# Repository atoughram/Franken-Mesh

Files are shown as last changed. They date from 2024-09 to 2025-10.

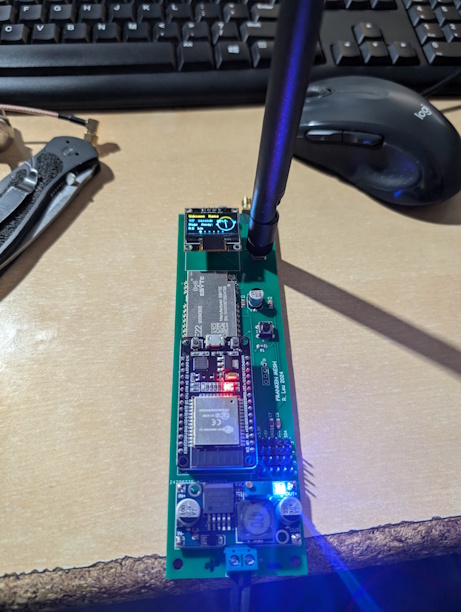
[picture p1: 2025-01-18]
images/PXL_20240928_021302629.jpg

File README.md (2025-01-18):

# Franken-Mesh
## DIY 1W LORA Node for Meshtastic

A Meshtastic project using a 30dbm (1W) LORA Radio (E22-900M30S) and an EPS32-DEVKIT-V1.  The circuit also adds four I2C ports for other sensors like a BME280 enviromental sensor, or any other sensor suported by Meshtastic.  There is also a TTL serial port for use with a GPS module and a ssd1306 connector if a Oled screen is wanted.

I've used this for both mobile and fixed operations with good luck.  There are STL files for a 3d printing a simple enclosure for the PCB.

![Franken-Mesh] (images/PXL_20240928_021302629.jpg) 

MIT License

Copyright (c) 2025 atoughram

Permission is hereby granted, free of charge, to any person obtaining a copy
of this software and associated documentation files (the "Software"), to deal
in the Software without restriction, including without limitation the rights
to use, copy, modify, merge, publish, distribute, sublicense, and/or sell
copies of the Software, and to permit persons to whom the Software is
furnished to do so, subject to the following conditions:

The above copyright notice and this permission notice shall be included in all
copies or substantial portions of the Software.

THE SOFTWARE IS PROVIDED "AS IS", WITHOUT WARRANTY OF ANY KIND, EXPRESS OR
IMPLIED, INCLUDING BUT NOT LIMITED TO THE WARRANTIES OF MERCHANTABILITY,
FITNESS FOR A PARTICULAR PURPOSE AND NONINFRINGEMENT. IN NO EVENT SHALL THE
AUTHORS OR COPYRIGHT HOLDERS BE LIABLE FOR ANY CLAIM, DAMAGES OR OTHER
LIABILITY, WHETHER IN AN ACTION OF CONTRACT, TORT OR OTHERWISE, ARISING FROM,
OUT OF OR IN CONNECTION WITH THE SOFTWARE OR THE USE OR OTHER DEALINGS IN THE
SOFTWARE.

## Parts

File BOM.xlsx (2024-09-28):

Description | Value | Reference | Qty | Footprint | Price | URL
Capacitor | 100nf | C2, C3, C4, C5, C7, C8, C9, C10 | 8 | Resistor_SMD:R_1206_3216Metric_Pad1.30x1.75mm_HandSolder | $1.26 | https://www.aliexpress.us/item/3256805505305288.html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
Capacitor | 100uf | C1, C6 | 2 | Capacitor_SMD:CP_Elec_6.3x7.7 | $1.62 | https://www.aliexpress.us/item/3256804775943180.html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
Resistor | 10K | R1 | 1 | Resistor_SMD:R_1206_3216Metric_Pad1.30x1.75mm_HandSolder | $1.07 | https://www.aliexpress.us/item/3256805494865143.html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
Microcontroller | ESP32-DEVKIT-V1 | U1 | 1 |  | $3.79 | https://www.aliexpress.us/item/3256802944254383.html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
30dbm LORA Radio | E22-900M30S | U2 | 1 |  | $7.39 | https://www.aliexpress.us/item/2255800357606493.html
SMA Connector |  | J7, J8 | 1 | Connector_Coaxial:SMA_Amphenol_901-144_Vertical | $2.31 | https://www.aliexpress.us/item/3256802990049867.html
Switch |  | SW1 | 1 | Button_Switch_THT:SW_PUSH_6mm | $0.25 | https://www.aliexpress.us/item/3256802876527512.html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
Display | SSD1306 |  | 1 |  | $1.65 | https://www.aliexpress.us/item/3256807290188213.html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
Buck Converter | LM2596 | U3 | 1 |  | $1.23 | https://www.aliexpress.us/item/3256806546818317.html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
Screw Terminal |  | J9 | 1 | TerminalBlock:TerminalBlock_bornier-2_P5.08mm | $1.32 | https://www.aliexpress.us/item/3256806456550715.html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
Male 5 pin Header |  | J3 - J6 | 4 | Connector_PinHeader_2.54mm:PinHeader_1x05_P2.54mm_Vertical | $1.91 | https://www.aliexpress.us/item/2255800687544049.html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
Female 15 pin Header |  |  | 2 |  | $1.91 | https://www.aliexpress.us/item/2255800687544049.html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

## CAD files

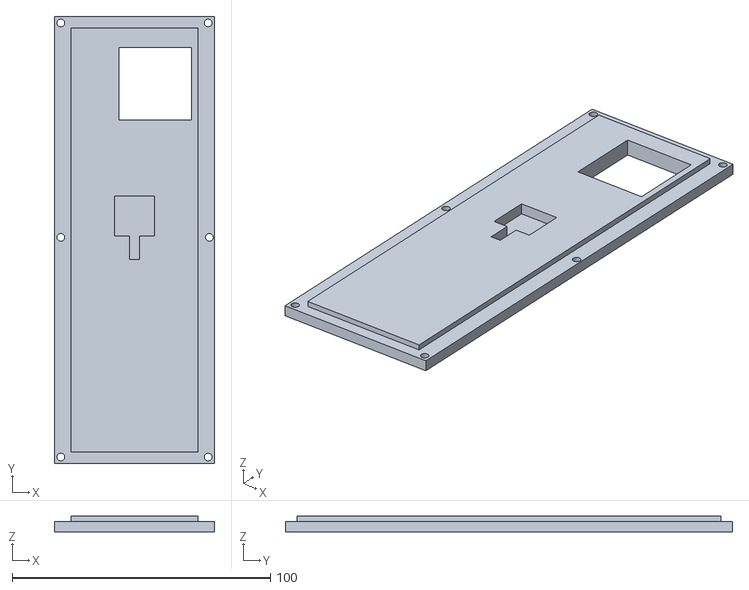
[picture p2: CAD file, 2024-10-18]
STL/Frankenmesh Top w GPS.stl
62.0 x 173.0 x 6.00

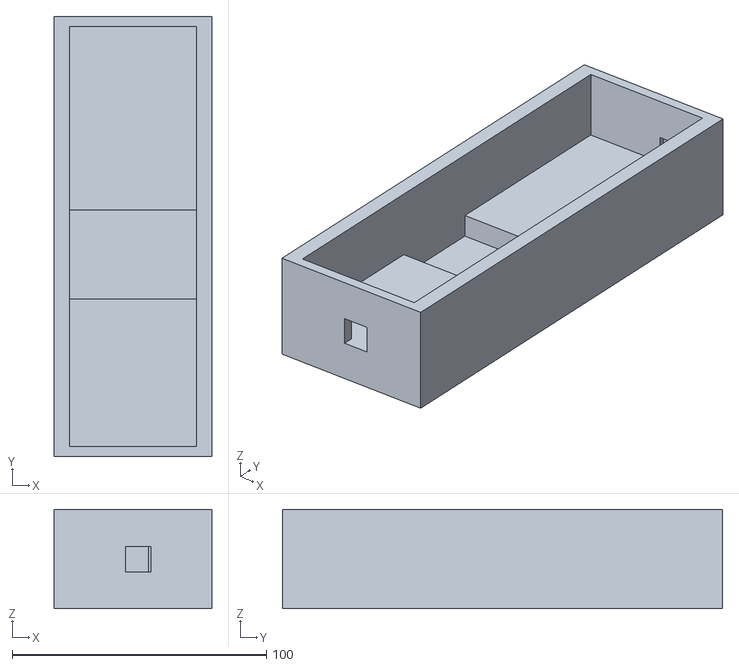
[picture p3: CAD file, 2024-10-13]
STL/Frankmesh Mobile Box Bottom with GPS.stl
62.0 x 173.0 x 39.0

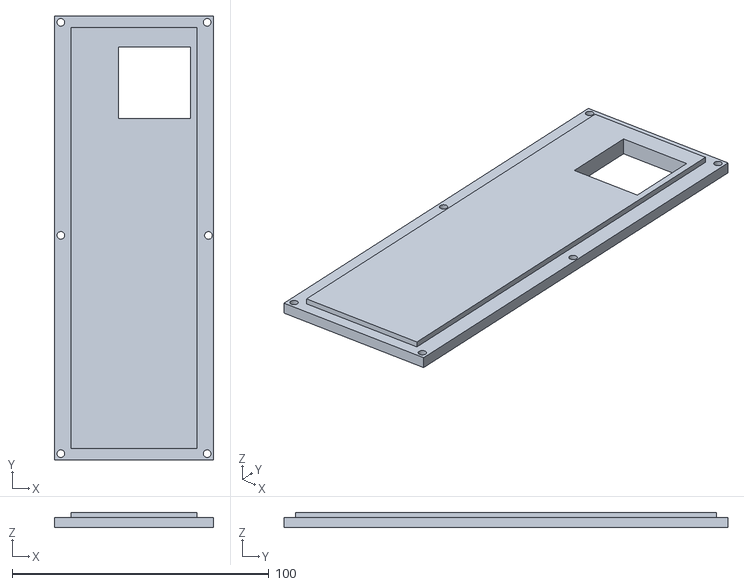
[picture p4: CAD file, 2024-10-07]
STL/Frankmesh Mobile Box Top (3).stl
62.0 x 173.0 x 6.00

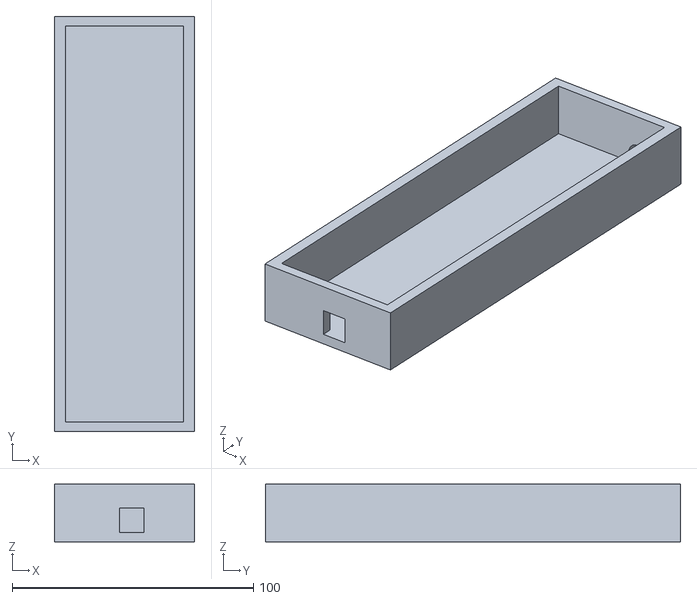
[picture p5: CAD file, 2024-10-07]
STL/Frankmesh Mobile Box Bottom (1).stl
58.0 x 172.0 x 24.0

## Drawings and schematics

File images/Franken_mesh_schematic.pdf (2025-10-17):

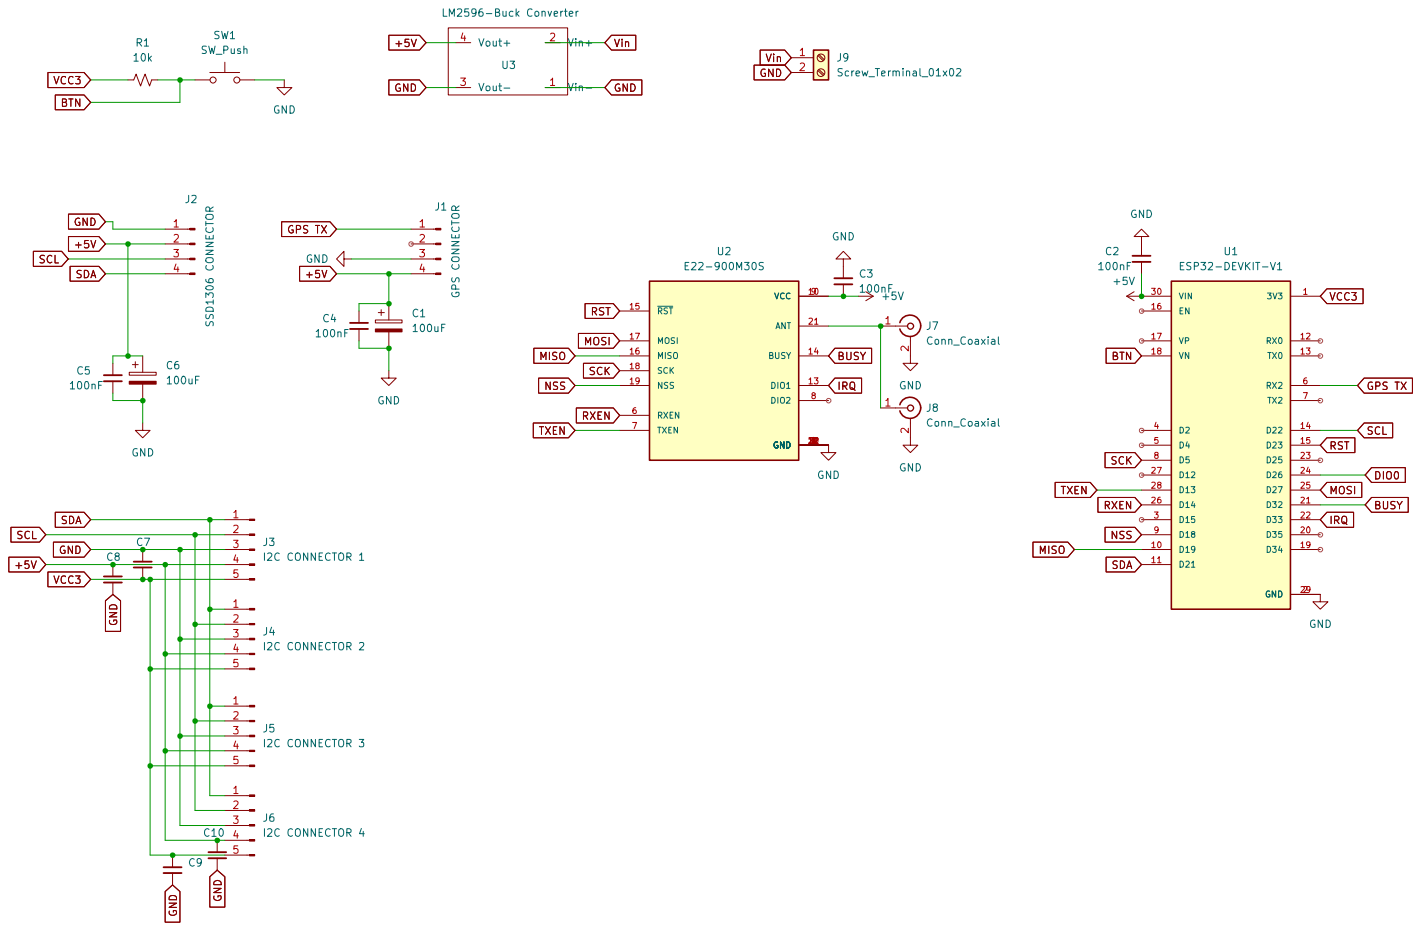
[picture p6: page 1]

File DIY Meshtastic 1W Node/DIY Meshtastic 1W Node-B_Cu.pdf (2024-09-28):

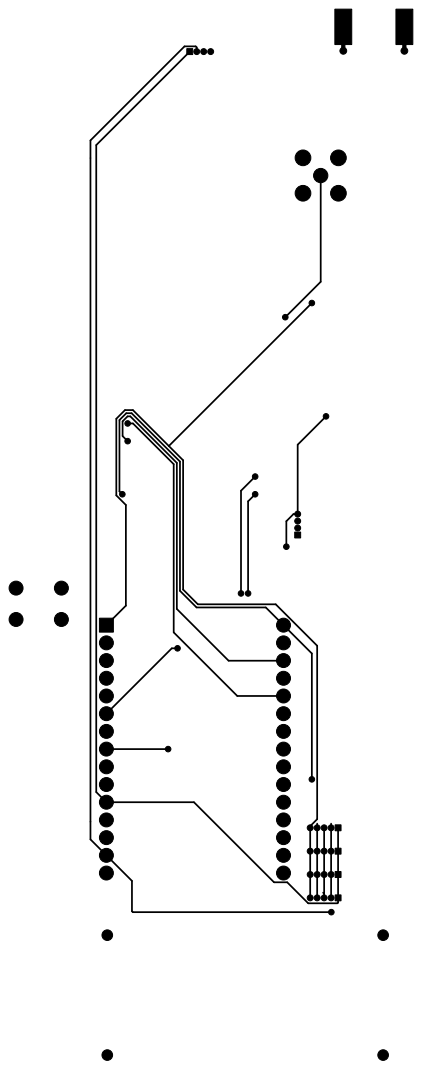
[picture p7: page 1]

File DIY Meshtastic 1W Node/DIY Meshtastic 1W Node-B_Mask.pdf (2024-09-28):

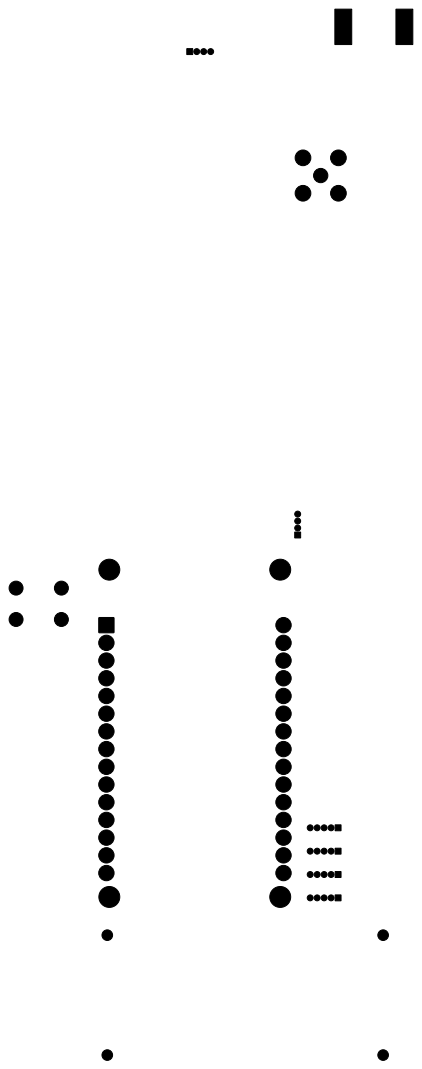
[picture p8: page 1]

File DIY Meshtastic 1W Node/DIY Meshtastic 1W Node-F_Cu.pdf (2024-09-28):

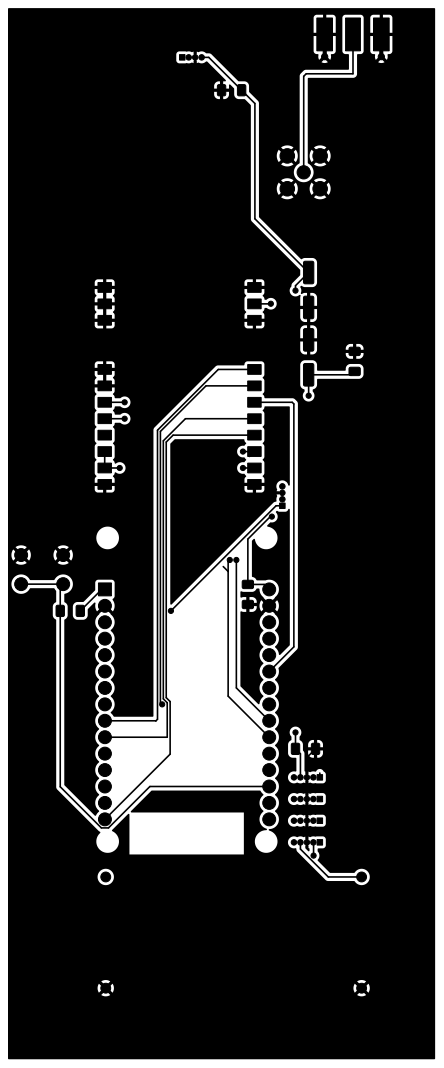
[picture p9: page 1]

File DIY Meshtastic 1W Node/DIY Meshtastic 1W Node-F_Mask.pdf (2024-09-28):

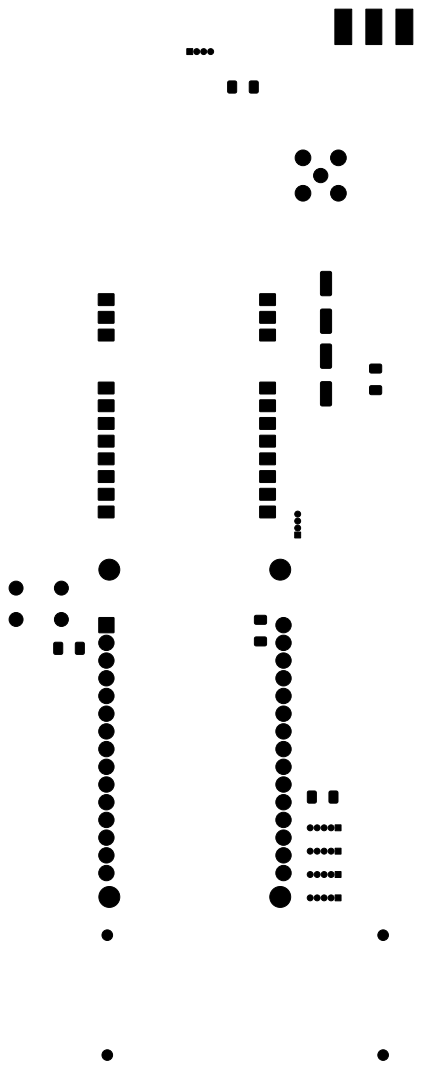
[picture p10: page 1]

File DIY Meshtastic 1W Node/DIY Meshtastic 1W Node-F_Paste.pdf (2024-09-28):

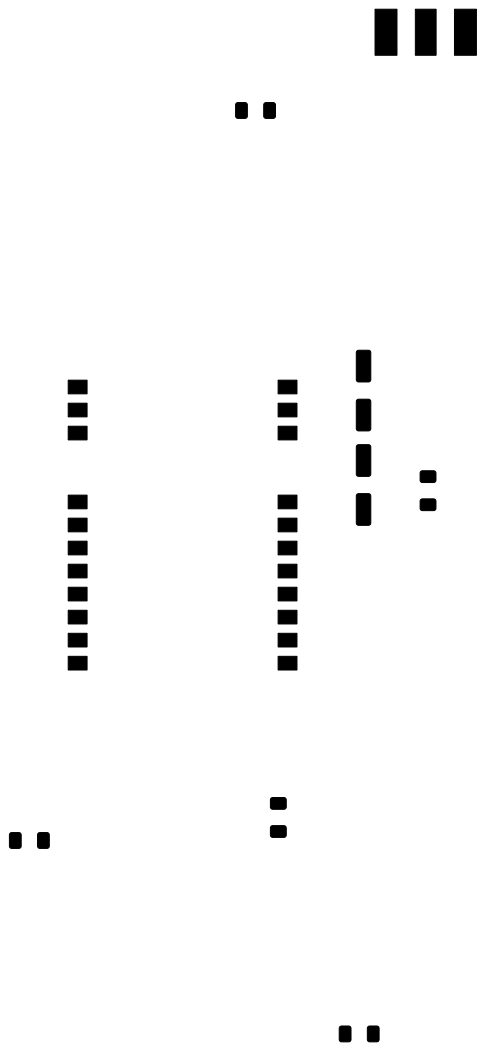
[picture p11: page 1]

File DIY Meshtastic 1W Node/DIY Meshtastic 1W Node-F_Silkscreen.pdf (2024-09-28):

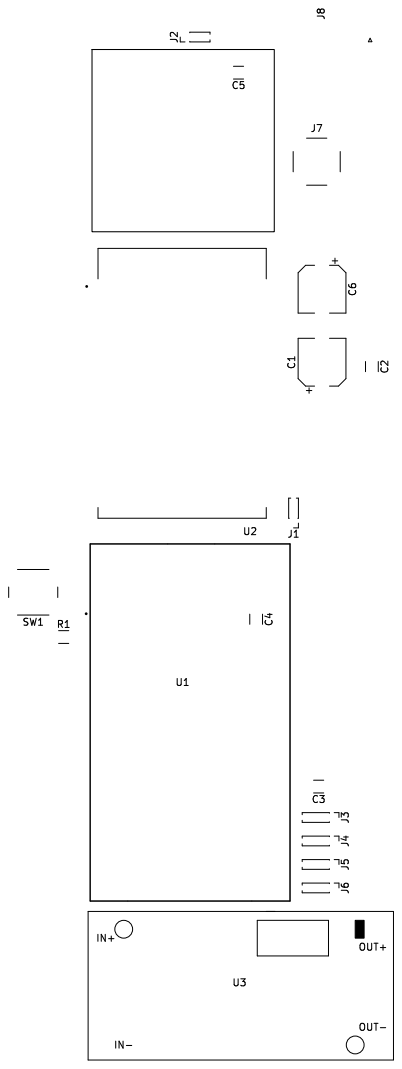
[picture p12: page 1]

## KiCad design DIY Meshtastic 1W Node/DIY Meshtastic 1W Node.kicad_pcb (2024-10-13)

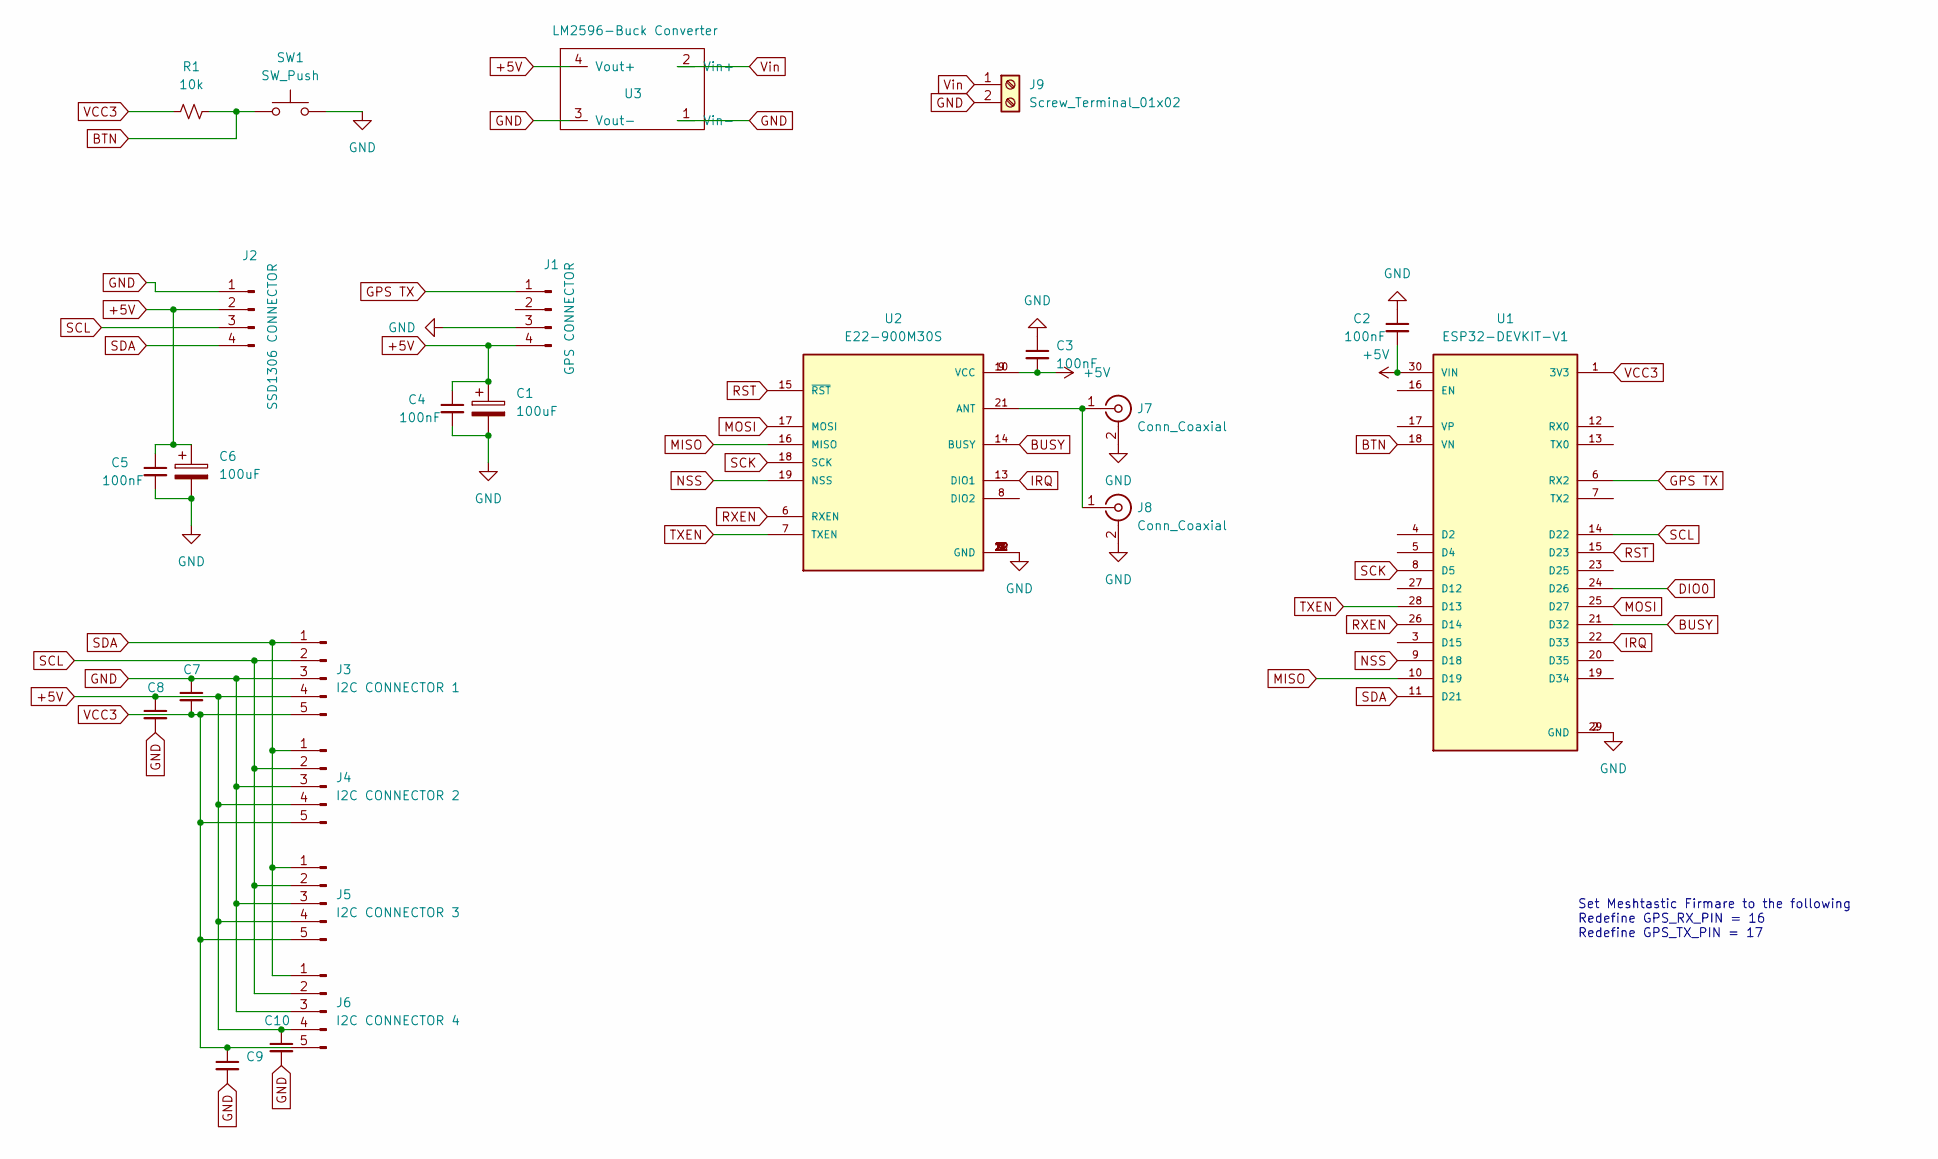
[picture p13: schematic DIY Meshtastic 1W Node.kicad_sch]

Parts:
C1, C6: 100uF; CP_Elec_6.3x7.7
C2, C3, C4, C5: 100nF; R_1206_3216Metric_Pad1.30x1.75mm_HandSolder
C7, C8, C9, C10: 100nf; R_1206_3216Metric_Pad1.30x1.75mm_HandSolder
J1: GPS CONNECTOR; PinHeader_1x04_P2.54mm_Vertical
J2: SSD1306 CONNECTOR; PinHeader_1x04_P2.54mm_Vertical
J3: I2C CONNECTOR 1; PinHeader_1x05_P2.54mm_Vertical
J4: I2C CONNECTOR 2; PinHeader_1x05_P2.54mm_Vertical
J5: I2C CONNECTOR 3; PinHeader_1x05_P2.54mm_Vertical
J6: I2C CONNECTOR 4; PinHeader_1x05_P2.54mm_Vertical
J7: Conn_Coaxial; SMA_Amphenol_901-144_Vertical
J8: Conn_Coaxial; SMA_Samtec_SMA-J-P-X-ST-EM1_EdgeMount
J9: Screw_Terminal_01x02; TerminalBlock_bornier-2_P5.08mm
R1: 10k; R_1206_3216Metric_Pad1.30x1.75mm_HandSolder
SW1: SW_Push; SW_PUSH_6mm
U1: ESP32-DEVKIT-V1; MODULE_ESP32_DEVKIT_V1; PARTREV N/A
U2: E22-900M30S; XCVR_E22-900M30S; PARTREV 1.2
U3: LM2596-Buck Converter; LM2596_HW_411

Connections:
+5V: C1.1, C2.2, C3.2, C4.1, C5.1, C6.1, C8.1, C10.1, J1.4, J2.2, J3.4, J4.4, J5.4, J6.4, U1.30 (VIN), U2.9 (VCC), U2.10 (VCC), U3.4 (Vout+)
BTN: R1.1, SW1.1, U1.18 (VN)
BUSY: U1.21 (D32), U2.14 (BUSY)
DIO0: U1.24 (D26)
GND: C1.2, C2.1, C3.1, C4.2, C5.2, C6.2, C7.1, C8.2, C9.2, C10.2, J1.3, J2.1, J3.3, J4.3, J5.3, J6.3, J7.2 (Ext), J8.2 (Ext), J9.2, SW1.2, U1.2 (GND), U1.29 (GND), U2.1 (GND), U2.2 (GND), U2.3 (GND), U2.4 (GND), U2.5 (GND), U2.11 (GND), U2.12 (GND), U2.20 (GND), U2.22 (GND), U3.1 (Vin-), U3.3 (Vout-)
GPS TX: J1.1, U1.6 (RX2)
IRQ: U1.22 (D33), U2.13 (DIO1)
MISO: U1.10 (D19), U2.16 (MISO)
MOSI: U1.25 (D27), U2.17 (MOSI)
NSS: U1.9 (D18), U2.19 (NSS)
unnamed: J7.1 (In), J8.1 (In), U2.21 (ANT)
RST: U1.15 (D23), U2.15 (~RST)
RXEN: U1.26 (D14), U2.6 (RXEN)
SCK: U1.8 (D5), U2.18 (SCK)
SCL: J2.3, J3.2, J4.2, J5.2, J6.2, U1.14 (D22)
SDA: J2.4, J3.1, J4.1, J5.1, J6.1, U1.11 (D21)
TXEN: U1.28 (D13), U2.7 (TXEN)
VCC3: C7.2, C9.1, J3.5, J4.5, J5.5, J6.5, R1.2, U1.1 (3V3)
Vin: J9.1, U3.2 (Vin+)

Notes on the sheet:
Set Meshtastic Firmare to the following Redefine GPS_RX_PIN = 16 Redefine GPS_TX_PIN = 17

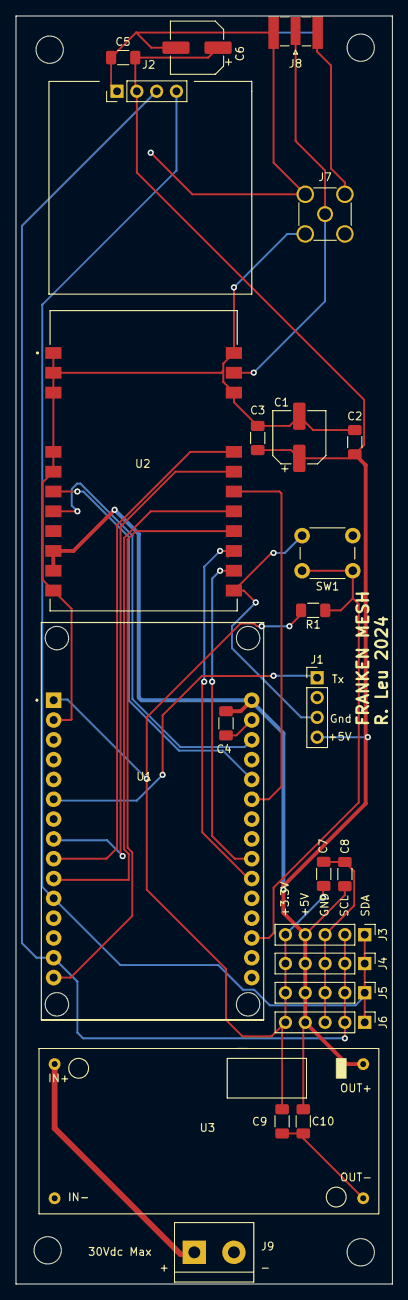
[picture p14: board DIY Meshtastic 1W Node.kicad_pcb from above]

Board: 2 copper layers, 48.3 x 162.6 mm, 24 parts (0 on the bottom side), 18 nets.

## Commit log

2024-09-28 Initial Commit
    Initial Commit
    [BOM.xlsx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]
2024-09-28 Minor Change to the schematic
    Add values for a couple of capacitors I forgot.
    [DIY Meshtastic 1W Node.kicad_sch]
2024-10-07 Added STL Files
    [BOM - Station G2 Node.xlsx, Frankmesh Mobile Box Bottom (1).stl, Frankmesh Mobile Box Top (3).stl]
2024-10-08 Modified the Schematic, and PCB
    Added some documentation on the schematic and PCB, regenerated gerbers
    [DIY Meshtastic 1W Node-B_Cu.gbl, DIY Meshtastic 1W Node-B_Mask.gbs, DIY Meshtastic 1W Node-B_Paste.gbp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]
2024-10-13 Incremental commit
    Fixed some of the front silkscreen and added an STL File
    [Frankmesh Mobile Box Bottom with GPS.stl]
2024-10-13 Updated Gerbers
    [DIY Meshtastic 1W Node-B_Cu.gbl, DIY Meshtastic 1W Node-B_Mask.gbs, DIY Meshtastic 1W Node-B_Paste.gbp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]
2024-10-18 Incremental Commit
    [Frankenmesh Top w GPS.stl]
2025-10-17 Added the Schematic
    in Images directory
